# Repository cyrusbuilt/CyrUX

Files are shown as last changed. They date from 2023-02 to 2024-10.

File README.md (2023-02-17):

# CyrUX


UX Add-on card (VGA, Audio, and PS/2) for the SC500-series computer system.

## Features
- VGA Display output
- - SVGA 1280x768 B&W @ 50Hz
- - SVGA 1024x768 4 colors @ 75Hz
- - SVGA 800x600 8 colors @ 56Hz
- - PAL 720x576 16 colors @ 50Hz
- - VGA 640x480 16 colors @ 73Hz
- - VGA 640x480 16 colors @ 60Hz
- - VGA 640x350 16 colors @ 70Hz
- - VGA 512x384 64 colors @ 60Hz
- - VGA 400x300 64 colors @ 60Hz
- PS/2 Keyboard and Mouse
- Amplified Mono Audio Output (using standard 3.5mm stereo/mono jack)
- OSD configuration GUI with mouse support
- Multiple terminal color options

At the heart of this board is an [ESP32](https://learn.adafruit.com/huzzah32-esp32-breakout-board) and the firmware was built using [FabGL](http://www.fabglib.org/). In fact, the firmware is essentially a customized version of the AnsiTerminal demo application in the FabGL library package. This board was specifically designed to work with [Stephen Cousin's SC500-series modular computer system](https://smallcomputercentral.com/modular-z50bus-system-sc500-series/), but since it really only requires the +5V, GND, and serial RX and TX pins of the [Z50 Bus](http://linc.no/products/z50bus/), you *could* connect it to something else using something like female-to-whatever dupont wires or a 50-pin IDC ribbon cable.  Essentially, this is *terminal* card and, as such, doesn't use memory mapped I/O. But it is interrupt-driven, uses both cores of the ESP32 and operates at 115200 BAUD, so it is quite fast.

## Hardware
Schematics, BOM, and production gerbers can be found in the 'schematics' folder and were created using [EasyEDA](https://easyeda.com/).

## Software
This project was built using [PlatformIO](https://platformio.org/) and the sources can be found in the 'src' and 'include' folders. As mentioned above, the firwmare makes extensive use of FabGL. There are a number of terminal escape sequences you can use to access graphics/audio/ADC/GPIO/etc features. See [FabGL Documentation](http://www.fabglib.org/special_term_escapes.html) for details.

## Jumpers
Jumper JP1 (Enable Bus Power) should be jumpered by default. You can remove this jumper if you want to power the board from the 6-pin programming/debug header (H1) using something like an [FTDI cable](https://www.adafruit.com/product/70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). This can be use for troubleshooting/debugging firmware issues without having the board plugged in to the SC500 backplane (standalone). Jumper JP3 (Enable RX) should also be jumpered by default. It may be useful to remove this jumper when flashing new firmware as I've had sporadic issues during the flashing process with the RX line connected (for reasons I have not yet identified). This jumper *may* be removed in a future revision.

## Building and Flashing the Firmware
The best way to do this is to leave the board unplugged from the SC500 backplane and then do the following:

1) Per the jumper documentation above, remove both jumpers.
2) Connect an FTDI cable (like the one linked above) to pin header H1 making sure to match the GND pin up and then plug the USB end in to your computer.
3) Make sure the monitor_port line in the platformio.ini is set to match the port for the FTDI cable on your machine.
4) Press both and hold both buttons on the ESP32 (see documentation for details) to put it in programming mode.
5) Enter the following command in your terminal at the root of the project folder:
```bash
> pio run --environment featheresp32 --target upload
```
6) Wait for the flashing process to complete, then disconnect the FTDI cable from the board.
7) Reinstall both jumpers.
8) Reinstall the board back into the backplane.
9) Power up the system and you're all set!

## Known Issues
When you first power on the system, you may see some jumbled output on the screen. This is because the host system and the CyrUX board are booting up at the same time and the serial connection will be out of sync at first. If this really bothers you, you can press the reset button on the host system to clear and re-initialize. If you want to see the CyrUX boot info screen, you can press F12 on your keyboard to access the OSD screen and click 'Reboot' to re-init the display. I may try to fix this in a future revision by holding the /RESET pin on the Z50 bus until CyrUX has a chance to finish booting first. However, the downside to this would be any time you reboot the display, you'd also reboot the host machine. Since this may not always be desirable behavior, it may be best to also add a jumper.

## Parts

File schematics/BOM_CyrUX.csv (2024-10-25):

ID | Name | Designator | Footprint | Quantity | Manufacturer Part | Manufacturer | Supplier | Supplier Part | Price
1 | 0.1uF | C1 | CAP-TH_L8.8-W3.6-P7.30-D0.5 | 1 | 0.1uF/250V | null | LCSC | C9900015263
2 | 10uF | C2 | ELECTROLYTIC CAPACITOR | 1 | electrolytic capacitor 10UF 50V high frequency | ValuePro | LCSC | C78759 | 0.014
3 | 100uF | C3 | ELECTROLYTIC CAPACITOR 100UF | 1
4 | 100nF | C4 | CAP-TH_L8.8-W3.6-P7.30-D0.5 | 1 | 0.1uF/250V | null | LCSC | C9900015263
5 | 2.2nF | C5 | CAP-TH_L8.8-W3.6-P7.30-D0.5 | 1 | 0.1uF/250V | null | LCSC | C9900015263
6 | 47nF | C6 | CAP-TH_L8.8-W3.6-P7.30-D0.5 | 1 | 0.1uF/250V | null | LCSC | C9900015263
7 | 220uF | C7 | 220UF ELECTROLYTIC | 1 | Aluminum electrolytic capacitors47uF 63V 20% High frequency green gold | ValuePro |  | C60712 | 0.023
8 | HEADER 1X6 | H1 | HEADER-1X6-2.54MM | 1
9 | ENABLE BUS POWER | JP1 | HDR1X2 | 1
10 | AUDIO-JACK PTH | JP2 | AUDIO-JACK | 1
11 | ENABLE RX | JP3 | HDR1X2 | 1
12 | PS/2 Connector | KEYBOARD,MOUSE | PS2_PORT | 2
13 | LM386 | LM386 | LM386 | 1 | LM386N-1/NOPB | LM386N-1/NOPB | Digi-Key
14 | HUZZAH-ESP32 | M1 | HUZZAH-ESP32 | 1
15 | OSHW-LOGOL | OPEN-HARDWARE | OSHW-LOGO-L | 1
16 | Z50Bus Card Plug Large | P1 | Z50BUS-HDR-2X25-A-M-2.54MM | 1
17 | 2N7000 | Q1,Q2,Q3 | 2N7000 TO-92 B | 3
18 | 220 | R1,R2 | PKG-0.25W RESISTOR | 2 | MCF 0.25W 150R | MULTICOMP | Element14 | 9339175
19 | 820 | R3,R5,R7 | PKG-0.25W RESISTOR | 3 | MCF 0.25W 150R | MULTICOMP | Element14 | 9339175
20 | 390 | R4,R6,R8 | PKG-0.25W RESISTOR | 3 | MCF 0.25W 150R | MULTICOMP | Element14 | 9339175
21 | 10k | R9,R10,R11,R12,R23,R24,R26,R27 | PKG-0.25W RESISTOR | 8 | MCF 0.25W 150R | MULTICOMP | Element14 | 9339175
22 | 120 | R13,R14,R15,R16 | PKG-0.25W RESISTOR | 4 | MCF 0.25W 150R | MULTICOMP | Element14 | 9339175
23 | 2k | R17,R18,R19,R20 | PKG-0.25W RESISTOR | 4 | MCF 0.25W 150R | MULTICOMP | Element14 | 9339175
24 | 270 | R21 | PKG-0.25W RESISTOR | 1 | MCF 0.25W 150R | MULTICOMP | Element14 | 9339175
25 | 150 | R22 | PKG-0.25W RESISTOR | 1 | MCF 0.25W 150R | MULTICOMP | Element14 | 9339175
26 | 10 | R25 | PKG-0.25W RESISTOR | 1 | MCF 0.25W 150R | MULTICOMP | Element14 | 9339175
27 | DSUB1 | VGA | D-SUB-TH_VGA-002 | 1 | VGA-002 | BOOMELE(博穆精密) | LCSC | C138387 | 0.21

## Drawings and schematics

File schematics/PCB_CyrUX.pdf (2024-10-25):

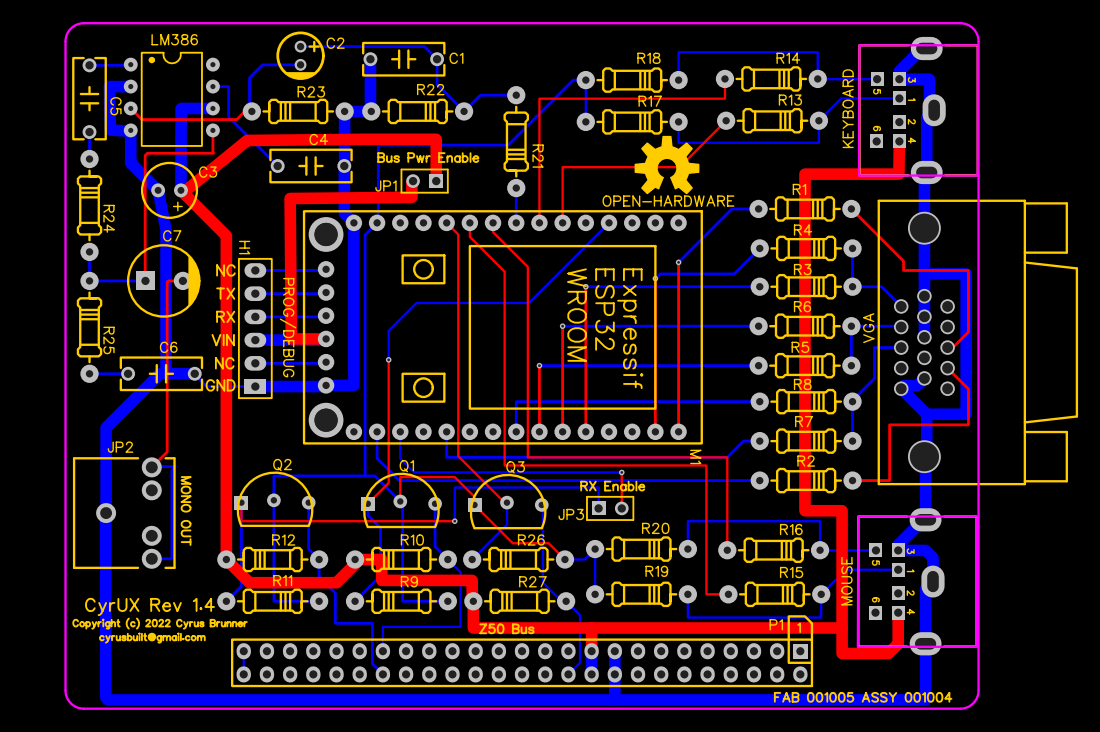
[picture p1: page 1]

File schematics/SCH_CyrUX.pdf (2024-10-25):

## MCU & SERIAL COMM. SECTION

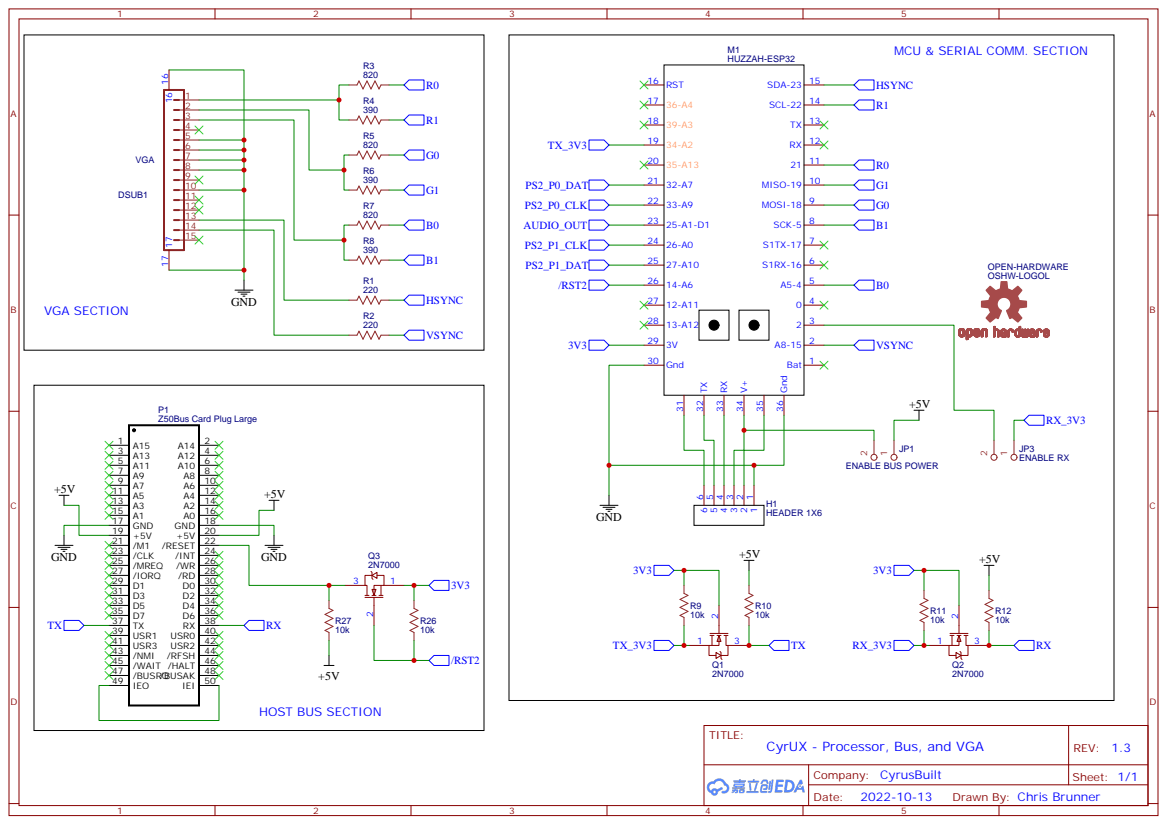
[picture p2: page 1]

Drawn By: Chris Brunner

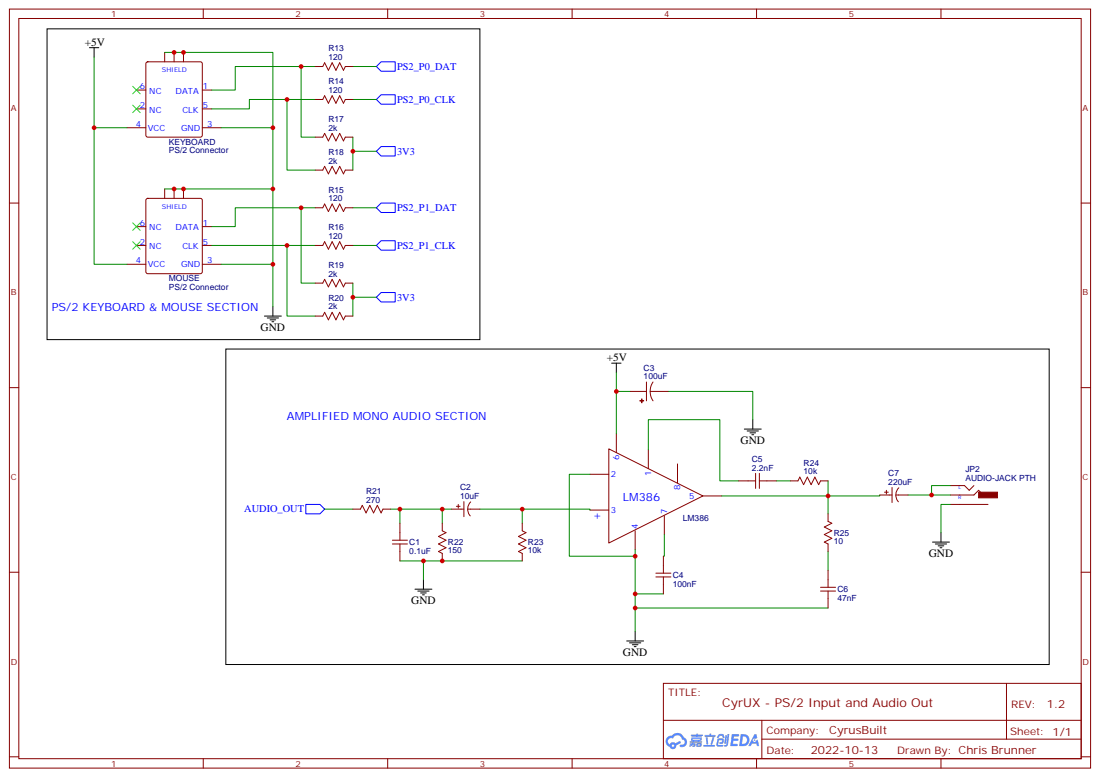
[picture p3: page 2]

PS/2 KEYBOARD & MOUSE SECTION

AMPLIFIED MONO AUDIO SECTION

Drawn By: Chris Brunner

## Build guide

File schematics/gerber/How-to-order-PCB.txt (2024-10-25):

How to Order PCB

Please refer to:
https://docs.easyeda.com/en/PCB/Order-PCB

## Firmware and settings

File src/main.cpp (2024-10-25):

/**
 * @file main.cpp
 * @author Cyrus Brunner (cyrusbuilt at gmail dot com)
 * @brief 
 * @version 1.2
 * @date 2022-10-21
 * 
 * @copyright Copyright (c) 2022
 * 
 */

#ifndef ESP32
	#error "This firmware is only intended to run on ESP32 MCUs."
#endif

#include "Arduino.h"
#include "fabgl.h"

fabgl::BitmappedDisplayController*  DisplayController;
fabgl::PS2Controller                PS2Controller;
fabgl::Terminal                     Terminal;
fabgl::SerialPort                   SerialPort;
fabgl::SerialPortTerminalConnector  SerialPortTerminalConnector;

#include "confdialog.h"

//#define DEBUG
#define INPUT_QUEUE_SIZE 2048     // 2048 good to pass vttest
#define KB_READER_STACK_SIZE 3000 // more stack is required for the UI (used inside Terminal.onVirtualKey)

void disableWatchdogs() {
	Serial.println("DEBUG: Disable watchdogs");
	disableCore0WDT();
  	delay(100); // experienced crashes without this delay!
  	disableCore1WDT();
}

void bootScreen() {
	if (ConfDialogApp::getBootInfo() == BOOTINFO_ENABLED) {
    	Terminal.write("* *  CyrUX - Serial Terminal                            * *\r\n");
    	Terminal.write("* *  2022 by Cyrus Brunner - cyrusbuilt@gmail.com       * *\r\n");
		Terminal.write("* *  Based on AnsiTerminal using FabGL                  * *\r\n");
		Terminal.write("* *  2019-2022 by Fabrizio Di Vittorio - www.fabgl.com  * *\r\n\n");
    	Terminal.printf("Version            : %d.%d\r\n", TERMVERSION_MAJ, TERMVERSION_MIN);
    	Terminal.printf("Screen Size        : %d x %d\r\n", DisplayController->getViewPortWidth(), DisplayController->getViewPortHeight());
    	Terminal.printf("Terminal Size      : %d x %d\r\n", Terminal.getColumns(), Terminal.getRows());
    	Terminal.printf("Keyboard Layout    : %s\r\n", PS2Controller.keyboard()->isKeyboardAvailable() ? SupportedLayouts::names()[ConfDialogApp::getKbdLayoutIndex()] : "No Keyboard");
    	Terminal.printf("Mouse              : %s\r\n", PS2Controller.mouse()->isMouseAvailable() ? "Yes" : "No");
    	Terminal.printf("Terminal Type      : %s\r\n", SupportedTerminals::names()[(int)ConfDialogApp::getTermType()]);
    	Terminal.printf("Term Free Memory   : %d bytes\r\n", heap_caps_get_free_size(MALLOC_CAP_32BIT));
    	Terminal.write("\r\nPress F12 to change terminal configuration and CTRL-ALT-F12 to reset settings\r\n\n");
  	} else if (ConfDialogApp::getBootInfo() == BOOTINFO_TEMPDISABLED) {
    	preferences.putInt(PREF_BOOTINFO, BOOTINFO_ENABLED);
  	}
}

void configureKeyboardEvents() {
	// onVirtualKey is triggered whenever a key is pressed or released
  	Terminal.onVirtualKeyItem = [&](VirtualKeyItem * vkItem) {
    	if (vkItem->vk == VirtualKey::VK_F12) {
      		// CTRL ALT F12 -> show reboot dialog
      		// F12          -> show configuration dialog
      		if (vkItem->CTRL && (vkItem->LALT || vkItem->RALT)) {
        		Terminal.deactivate();
        		preferences.clear();

        		// show reboot dialog
        		auto rebootApp = new RebootDialogApp;
        		rebootApp->run(DisplayController);
      		}
			else if (!vkItem->CTRL && !vkItem->LALT && !vkItem->RALT && !vkItem->down) {
        		// releasing F12 key to open configuration dialog
        		Terminal.deactivate();
        		if (PS2Controller.mouse()) {
          			PS2Controller.mouse()->emptyQueue();  // avoid previous mouse movements to be showed on UI
				}
        		
				auto dlgApp = new ConfDialogApp;
        		dlgApp->run(DisplayController);
        		
        		// this is required, because the terminal may not cover the entire screen
        		Terminal.canvas()->reset();
        		Terminal.canvas()->setBrushColor(dlgApp->getBGColor());
        		Terminal.canvas()->fillRectangle(dlgApp->frameRect);        
        		delete dlgApp;

        		Terminal.keyboard()->emptyVirtualKeyQueue();
        		Terminal.activate();
        		
        		vkItem->vk = VirtualKey::VK_NONE;
      		}
    	}
		else if (vkItem->vk == VirtualKey::VK_BREAK && !vkItem->down) {
      		// BREAK (CTRL PAUSE) -> short break (TX low for 3.5 s)
      		// SHIFT BREAK (SHIFT CTRL PAUSE) -> long break (TX low for 0.233 ms)
      		SerialPort.sendBreak(true);
      		vTaskDelay((vkItem->SHIFT ? 3500 : 233) / portTICK_PERIOD_MS);
      		SerialPort.sendBreak(false);
      		vkItem->vk = VirtualKey::VK_NONE;
    	}
  	};

  	// onUserSequence is triggered whenever a User Sequence has been received (ESC + '_#' ... '$'), where '...' is sent here
  	Terminal.onUserSequence = [&](char const * seq) {
    	// 'R': change resolution (for example: ESC + "_#R512x384x64$")
    	for (int i = 0; i < RESOLUTIONS_COUNT; ++i) {
      		if (strcmp(RESOLUTIONS_CMDSTR[i], seq) == 0) {
        		// found resolution string
        		preferences.putInt(PREF_TEMPRESOLUTION, i);
        		if (ConfDialogApp::getBootInfo() == BOOTINFO_ENABLED) {
          			preferences.putInt(PREF_BOOTINFO, BOOTINFO_TEMPDISABLED);
				}

        		ESP.restart();
      		}
		}
  	};
}

void setup() {
	// Hold reset
	pinMode(PIN_RST, OUTPUT);
	digitalWrite(PIN_RST, LOW);

	Serial.begin(115200);
	delay(500);

	disableWatchdogs();

  	Terminal.keyboardReaderTaskStackSize = KB_READER_STACK_SIZE;
	Terminal.inputQueueSize = INPUT_QUEUE_SIZE;
	
	preferences.begin("CyrUX", false);

  	ConfDialogApp::checkVersion();

	// because mouse is optional, don't re-try if it is not found (to speed-up boot)
  	fabgl::Mouse::quickCheckHardware();

	// Keyboard on PS/2 Port 0, mouse on Port 1.
	PS2Controller.begin(PS2Preset::KeyboardPort0_MousePort1);

	ConfDialogApp::setupDisplay();
  	ConfDialogApp::loadConfiguration();

	Terminal.clear();
  	Terminal.enableCursor(true);

	bootScreen();

	configureKeyboardEvents();

	// Release reset
	digitalWrite(PIN_RST, HIGH);
}

void loop() {
	// the job is done using UART interrupts
  	vTaskDelete(NULL);
}

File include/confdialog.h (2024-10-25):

#ifndef _CONFDIALOG_H
#define _CONFDIALOG_H

#include <Preferences.h>
#include "Arduino.h"
#include "fabgl.h"
#include "fabui.h"
#include "uistyle.h"
#include "restartdialog.h"

#define TERMVERSION_MAJ 1
#define TERMVERSION_MIN 2

// IMPORTANT NOTE: The TX/RX pin assignments here are inverted from the Net Labels.
// This is for 2 reasons: 1) pin 34 can *only* be an input, therefore can only be
// used for RX. 2) Since the Z50 bus is transmitting on pin 37 (TX), the pin it
// ties to should be RX, and vice-versa for pin 2 (TX) on the ESP32 and pin 38 (RX)
// on the Z50 bus.
#define PIN_RX 34  
#define PIN_TX 2
#define PIN_RST 14
#define TERM_BAUD_RATE 115200
#define TERM_DATA_BITS 8
#define TERM_STOP_BITS 1
#define TERM_PARITY 'N'

constexpr int RESOLUTION_DEFAULT = 5;

static const char * RESOLUTIONS_STR[] = {
	"1280x768, B&W",           // 0
  "1024x720, 4 Colors",      // 1
  "800x600, 8 Colors",       // 2
  "720x520, 16 Colors",      // 3
  "640x480 73Hz, 16 C.",     // 4
  "640x480 60Hz, 16 C.",     // 5
  "640x350, 16 Colors",      // 6
  "512x384, 64 Colors",      // 7
  "400x300, 64 Colors",      // 8
};

static const char * RESOLUTIONS_CMDSTR[] = {
  "1280x768x2",              // 0
  "1024x720x4",              // 1
  "800x600x8",               // 2
	"720x520x16",              // 3
  "640x480@73x16",           // 4
  "640x480@60x16",           // 5
  "640x350x16",              // 6
  "512x384x64",              // 7
  "400x300x64",              // 8
};

enum class ResolutionController {
	VGAController,
	VGA16Controller,
	VGA8Controller,
	VGA2Controller,
	VGA4Controller
};

static const ResolutionController RESOLUTIONS_CONTROLLER[] = {
	ResolutionController::VGA2Controller,     // 0
  ResolutionController::VGA4Controller,     // 1
  ResolutionController::VGA8Controller,     // 2
  ResolutionController::VGA16Controller,    // 3
  ResolutionController::VGA16Controller,    // 4
  ResolutionController::VGA16Controller,    // 5
  ResolutionController::VGA16Controller,    // 6
  ResolutionController::VGAController,      // 7
  ResolutionController::VGAController,      // 8
};

static const char * RESOLUTIONS_MODELINE[] = {
	SVGA_1280x768_50Hz,        // 0
  SVGA_1024x768_75Hz,        // 1
  SVGA_800x600_56Hz,         // 2
  PAL_720x576_50Hz,          // 3
  VGA_640x480_73Hz,          // 4
  VGA_640x480_60Hz,          // 5
  VGA_640x350_70HzAlt1,      // 6
  VGA_512x384_60Hz,          // 7
  VGA_400x300_60Hz,          // 8
};

static const int16_t RESOLUTIONS_HEIGHT[] = {
	-1,        // 0
  720,       // 1
  -1,        // 2
  520,       // 3
  -1,        // 4
  -1,        // 5
  -1,        // 6
  -1,        // 7
  -1,        // 8
};

constexpr int RESOLUTIONS_COUNT = sizeof(RESOLUTIONS_STR) / sizeof(char const *);

static const char * FONTS_STR[] = { "Auto", "VGA 4x6", "VGA 5x7", "VGA 5x8", "VGA 6x8", "VGA 6x9", "VGA 6x10", "VGA 6x12", "VGA 6x13",
                                    "VGA 7x13", "VGA 7x14", "VGA 8x8", "VGA 8x9", "VGA 8x13", "VGA 8x14", "VGA 8x16", "VGA 8x19", "VGA 9x15",
                                    "VGA 9x18", "VGA 10x20", "BigSerif 8x14", "BigSerif 8x16", "Block 8x14", "Broadway 8x14",
                                    "Computer 8x14", "Courier 8x14", "LCD 8x14", "Old English 8x16", "Sans Serif 8x14", "Sans Serif 8x16",
                                    "Slant 8x14", "Wiggly 8x16" };

static const fabgl::FontInfo* FONTS_INFO[] = { nullptr, &fabgl::FONT_4x6, &fabgl::FONT_5x7, &fabgl::FONT_5x8, &fabgl::FONT_6x8, &fabgl::FONT_6x9,
                                               &fabgl::FONT_6x10, &fabgl::FONT_6x12, &fabgl::FONT_6x13, &fabgl::FONT_7x13, &fabgl::FONT_7x14, &fabgl::FONT_8x8,
                                               &fabgl::FONT_8x9, &fabgl::FONT_8x13, &fabgl::FONT_8x14, &fabgl::FONT_8x16, &fabgl::FONT_8x19, &fabgl::FONT_9x15,
                                               &fabgl::FONT_9x18, &fabgl::FONT_10x20, &fabgl::FONT_BIGSERIF_8x14, &fabgl::FONT_BIGSERIF_8x16, &fabgl::FONT_BLOCK_8x14,
                                               &fabgl::FONT_BROADWAY_8x14, &fabgl::FONT_COMPUTER_8x14, &fabgl::FONT_COURIER_8x14,
                                               &fabgl::FONT_LCD_8x14, &fabgl::FONT_OLDENGL_8x16, &fabgl::FONT_SANSERIF_8x14, &fabgl::FONT_SANSERIF_8x16,
                                               &fabgl::FONT_SLANT_8x14, &fabgl::FONT_WIGGLY_8x16 };

constexpr int FONTS_COUNT = sizeof(FONTS_STR) / sizeof(char const *);

static const char * COLUMNS_STR[] = { "Max", "80", "132" };
static const int    COLUMNS_INT[] = { 0, 80, 132 };
constexpr int       COLUMNS_COUNT = sizeof(COLUMNS_STR) / sizeof(char const *);

static const char * ROWS_STR[]    = { "Max", "24", "25" };
static const int    ROWS_INT[]    = { 0, 24, 25 };
constexpr int       ROWS_COUNT    = sizeof(ROWS_STR) / sizeof(char const *);

constexpr int       BOOTINFO_DISABLED     = 0;
constexpr int       BOOTINFO_ENABLED      = 1;
constexpr int       BOOTINFO_TEMPDISABLED = 2;

// preferences keys
static const char * PREF_VERMAJ         = "VerMaj";
static const char * PREF_VERMIN         = "VerMin";
static const char * PREF_TERMTYPE       = "TermType";
static const char * PREF_KBDLAYOUT      = "KbdLayout";
static const char * PREF_BGCOLOR        = "BGColor";
static const char * PREF_FGCOLOR        = "FGColor";
static const char * PREF_RESOLUTION     = "Resolution";
static const char * PREF_FONT           = "Font";
static const char * PREF_COLUMNS        = "Columns";
static const char * PREF_ROWS           = "Rows";
static const char * PREF_BOOTINFO       = "BootInfo";
static const char * PREF_TEMPRESOLUTION = "TempResolution";

Preferences preferences;
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

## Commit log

2022-10-18 Initial design commit
    [BOM_CyrUX.csv]
2022-10-20 GND copper fill, fix keyb circuit, gerbers
    [Drill_NPTH_Through.DRL, Drill_PTH_Through.DRL, Gerber_BoardOutlineLayer.GKO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]
2022-11-01 PS/2 and R9-R12 orientation. Initial FW.
    [BOM_CyrUX.csv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]
2023-01-01 Design and bug fixes for kbd, mouse, and serial
    [BOM_CyrUX.csv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]
2023-01-25 Fix swapped RX/TX lines
    [Drill_NPTH_Through.DRL, Drill_PTH_Through.DRL, Drill_PTH_Through_Via.DRL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]
2024-10-25 Hold reset during board init
    [BOM_CyrUX.csv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]
